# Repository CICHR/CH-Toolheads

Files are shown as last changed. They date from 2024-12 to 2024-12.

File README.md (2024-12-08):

CICHR Toolheads

The changeable toolheads are designed for maximum versatility and seamless integration, communicating directly with the printer via a custom PCB. This PCB enables precise control and coordination between the tool head and the printer, ensuring fast, accurate swaps between different functions. The custom PCB features:

    Heater and High-Power Outputs:
    Two high-power outputs for heaters or PWM-controlled devices with demanding power requirements.

    Temperature Sensing:
    Two thermistor inputs for accurate real-time temperature monitoring.

    PWM Outputs:
    Two PWM outputs for controlling servos, BLTouch sensors, or cooling fans.

    Digital Interfaces:
    One digital input and one digital output for additional functionality, such as endstops or status signaling.

    Stepper Motor Control:
    A dedicated output for driving a single stepper motor, ideal for toolhead-mounted extrusion or positioning tasks.

    Streamlined Communication:
    Ensures reliable communication between the toolhead and the machine, simplifying toolhead management and enhancing modularity.

This system allows you to quickly swap between different toolheads, such as 3D printing extruders, CNC milling tools, lasers, or liquid extruders, without complex rewiring, while maintaining full control over key functions.

Visit our website at www.cichr.com or https://grabcad.com/cichr-1 to learn more about our products, projects, and innovations.

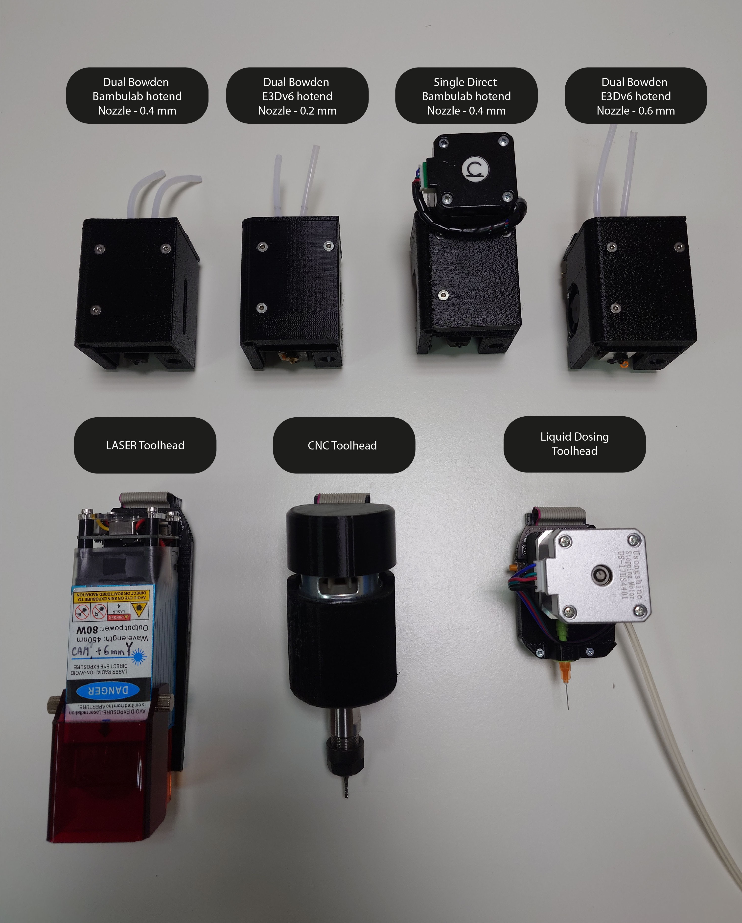
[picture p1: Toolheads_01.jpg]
CH-Toolheads


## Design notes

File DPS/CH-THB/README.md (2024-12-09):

CH-THB: The Versatile Toolhead PCB

The CH-THB is a specialized PCB board designed to manage and control a single toolhead, seamlessly connecting it to the main machine control system. This board is highly versatile, supporting various toolhead types, including 3D printers, lasers, routers, and more.

  Key Features:

      Heater and High-Power Outputs:
        Two high-power outputs for heaters or PWM-controlled devices with demanding power requirements.
      Temperature Sensing:
        Two thermistor inputs for accurate real-time temperature monitoring.
      PWM Outputs:
        Two PWM outputs for controlling servos, BLTouch sensors, or cooling fans.
      Digital Interfaces:
        One digital input and one digital output for additional functionality, such as endstops or status signaling.
      Stepper Motor Control:
        A dedicated output for driving a single stepper motor, ideal for toolhead-mounted extrusion or positioning tasks.
      Streamlined Communication:
        Ensures reliable communication between the toolhead and the machine, simplifying toolhead management and enhancing modularity.

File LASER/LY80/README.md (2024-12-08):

The CH-LASER-LY80 toolhead is a versatile and powerful laser module, perfect for cutting and engraving a wide range of materials with precision and efficiency. Featuring the LUNYEE 80W blue diode laser with a 10W optical power output, it delivers exceptional accuracy for both hobbyists and professionals. A built-in WiFi camera ensures precise alignment and real-time monitoring for flawless results.

    Cutting Capabilities:
    All types of paper, carton, fabric, leather, and plastics (note: NEVER laser PVC as it releases toxic fumes).
    Soft and medium-hard woods up to 10–12mm with multiple passes; 3–5mm achievable in a single pass.
    Black and certain colored acrylics up to 5mm with ease, 10mm depending on the color (clear acrylic cannot be cut due to the laser's light frequency).

    Engraving Capabilities:
    Almost all non-metallic materials.
    Stainless steel and ceramics with remarkable precision.

The CH-LASER-LY80 is the perfect toolhead for achieving high-quality cuts and engravings across a wide variety of projects.

Visit our website at www.cichr.com or https://grabcad.com/cichr-1 to learn more about our products, projects, and innovations.

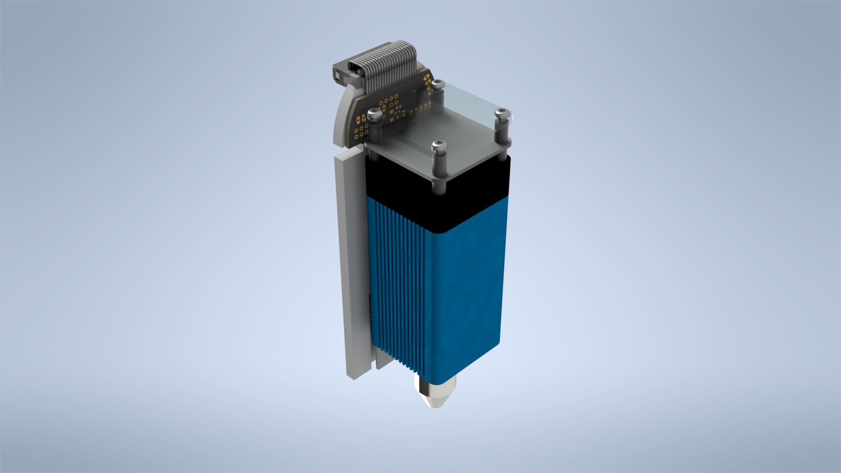
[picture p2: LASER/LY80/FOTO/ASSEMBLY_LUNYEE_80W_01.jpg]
CH-LASER-LY80


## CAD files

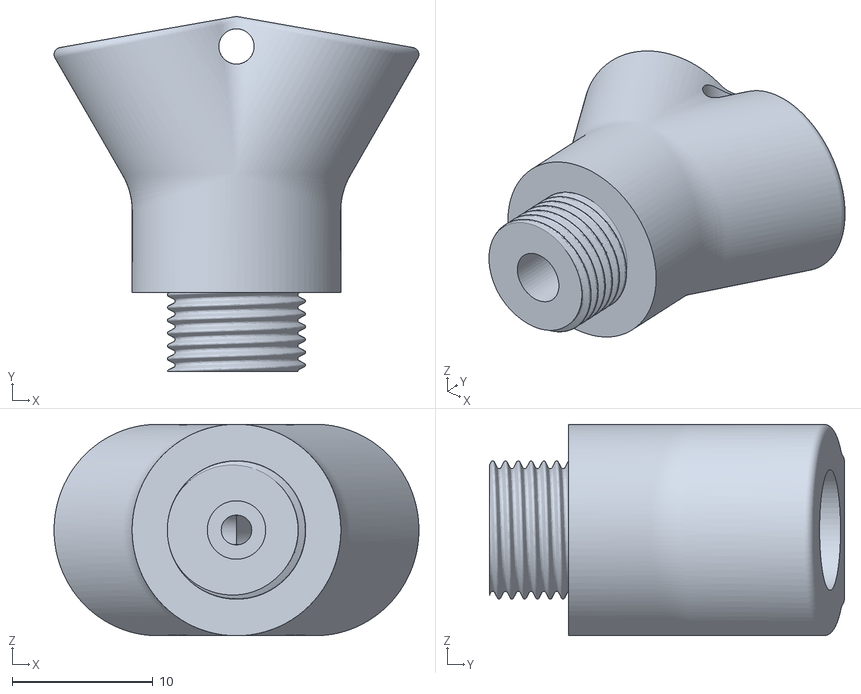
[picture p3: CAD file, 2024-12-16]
3D_PRINT/E3D_BOWDEN/STL/E3Dv6_DUAL_FITTING.stl
25.9 x 25.2 x 15.0

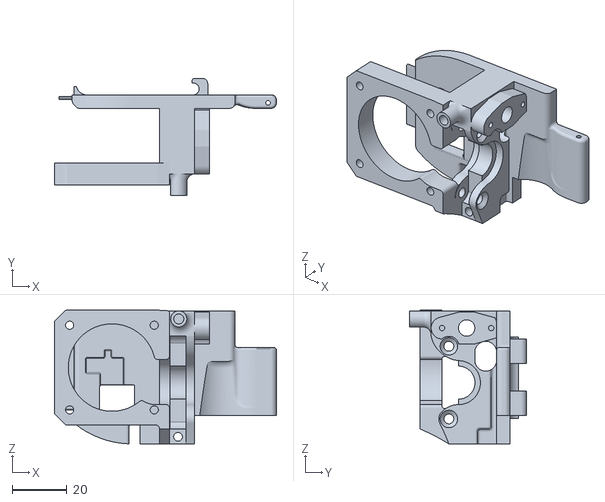
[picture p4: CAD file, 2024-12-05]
3D_PRINT/E3D_DIRECT/STL/E3Dv6_DIRECT_BASE.stl
81.3 x 43.0 x 49.0

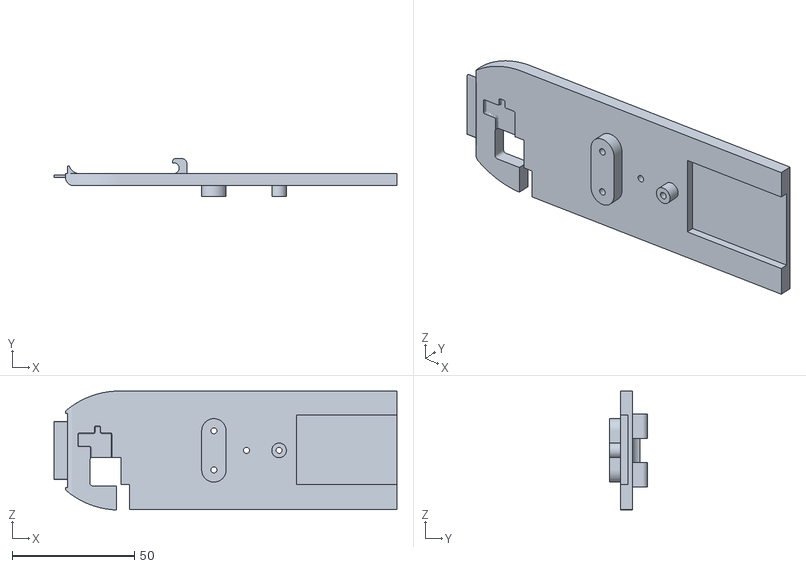
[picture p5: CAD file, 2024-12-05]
LASER/LY80/STL/X_Mount_LUNYEE_80W.stl
140.5 x 15.5 x 48.7

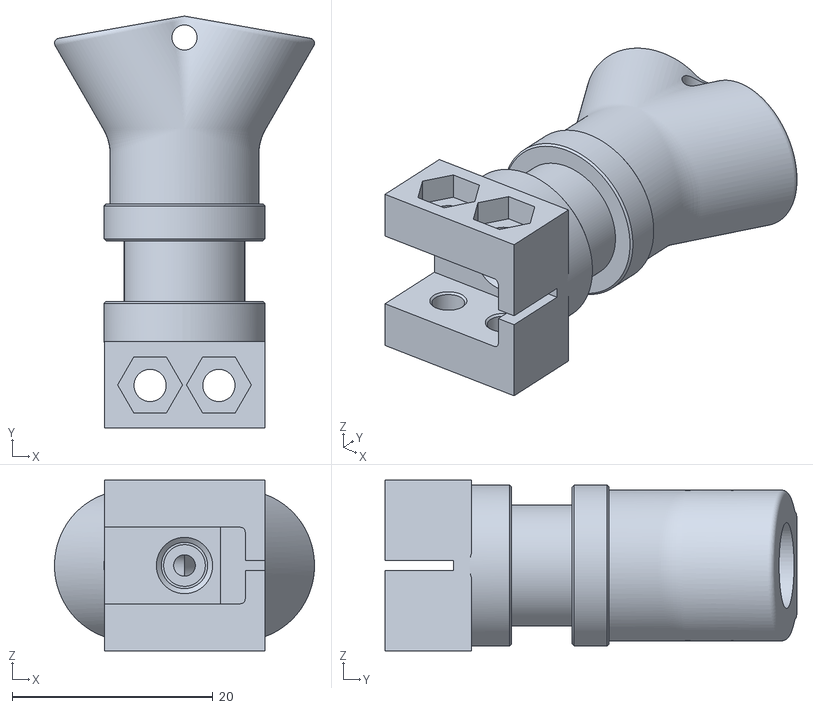
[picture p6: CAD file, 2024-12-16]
3D_PRINT/E3D_BOWDEN/STL/ADAPTER_BAMBU-E3D_DUAL_FITTING.stl
25.9 x 41.0 x 17.0

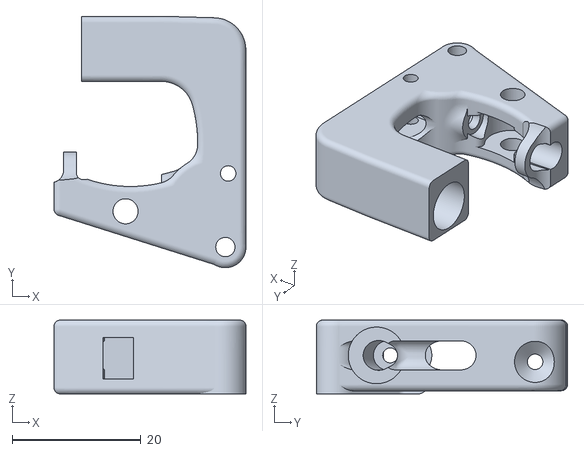
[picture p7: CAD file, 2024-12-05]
3D_PRINT/E3D_DIRECT/STL/E3Dv6_DIRECT_TENSIONER_II.stl
29.9 x 39.1 x 11.5

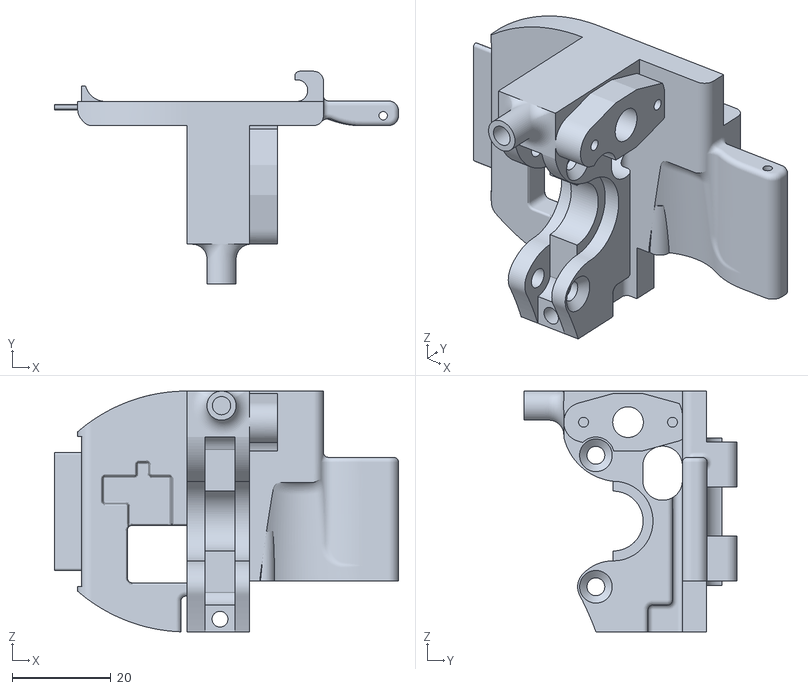
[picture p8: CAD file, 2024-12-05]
3D_PRINT/E3D_BOWDEN/STL/E3Dv6_BOWDEN_BASE.stl
69.6 x 43.0 x 48.7

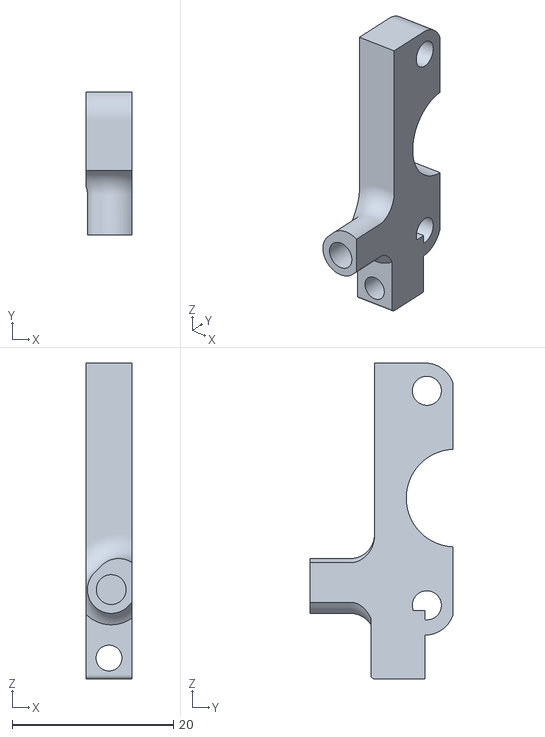
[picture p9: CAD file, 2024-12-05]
3D_PRINT/E3D_DIRECT/STL/E3Dv6_DIRECT_BASE_Bracket.stl
5.75 x 17.8 x 39.2

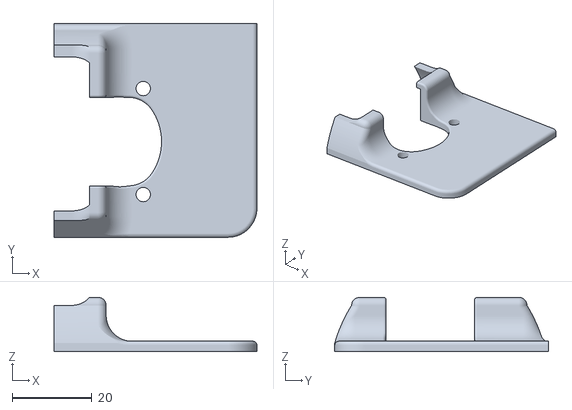
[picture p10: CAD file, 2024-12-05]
3D_PRINT/E3D_BOWDEN/STL/E3Dv6_BOWDEN_HOUSING_Top_DUAL.stl
50.9 x 53.6 x 13.6

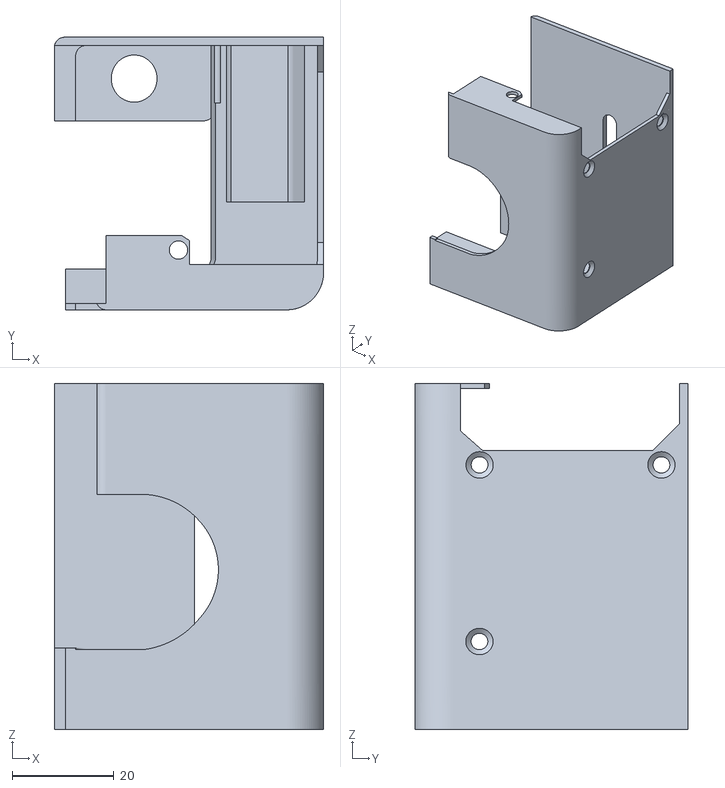
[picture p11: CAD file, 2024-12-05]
3D_PRINT/E3D_DIRECT/STL/E3Dv6_DIRECT_HOUSING_Side.stl
53.0 x 53.6 x 68.0

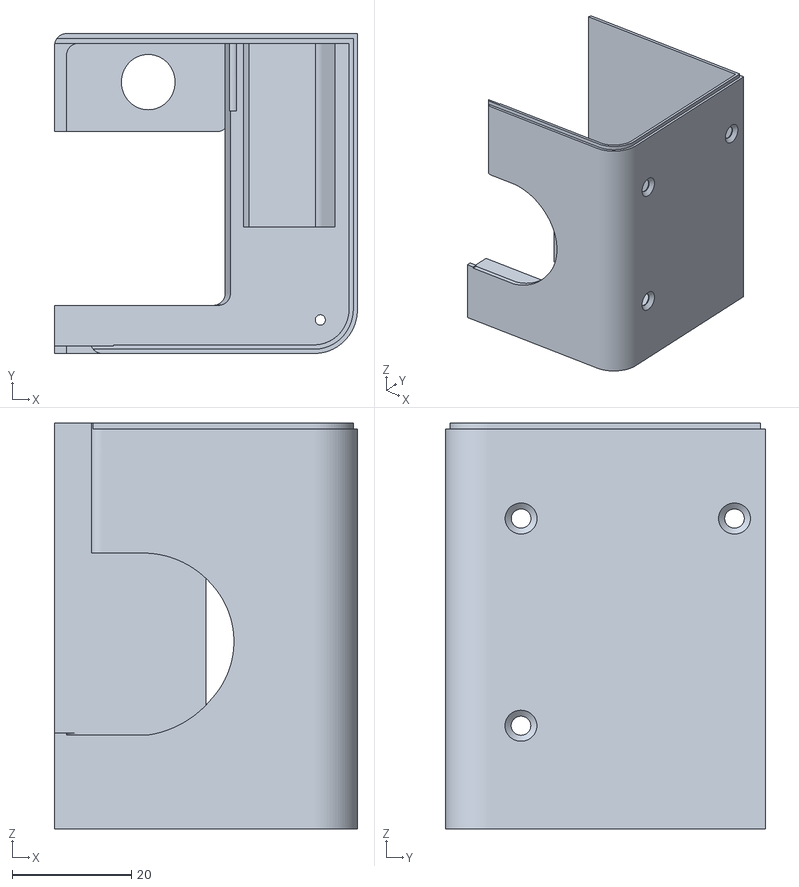
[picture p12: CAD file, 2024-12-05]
3D_PRINT/E3D_BOWDEN/STL/E3Dv6_BOWDEN_HOUSING_Side.stl
50.8 x 53.6 x 68.0

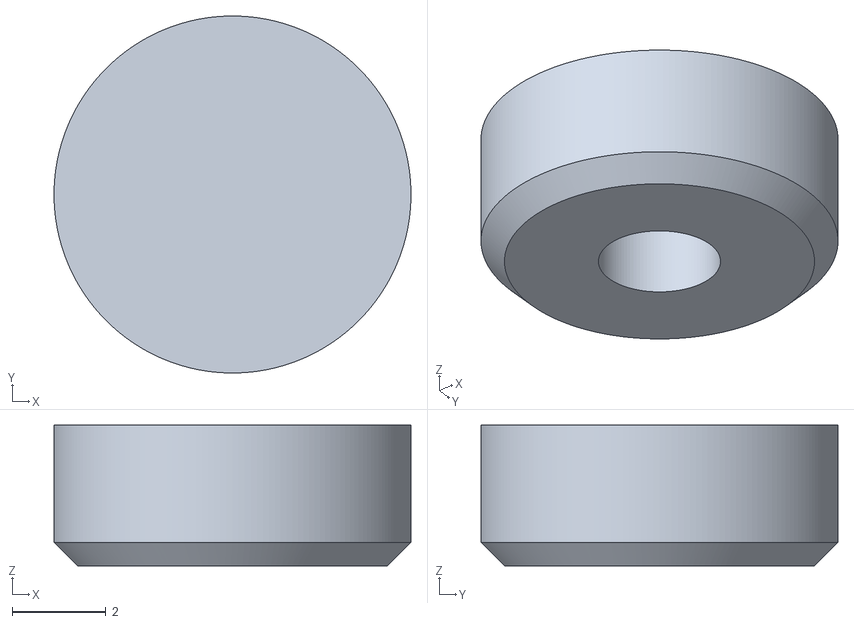
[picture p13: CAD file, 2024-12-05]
3D_PRINT/E3D_DIRECT/STL/E3Dv6_DIRECT_LoadPad.stl
7.60 x 7.60 x 3.00

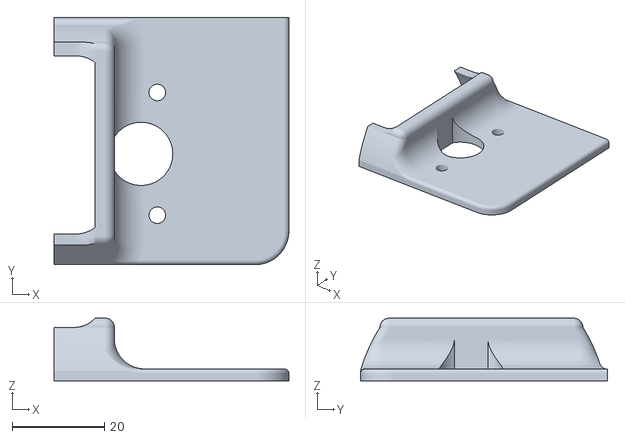
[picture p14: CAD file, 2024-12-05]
3D_PRINT/E3D_BOWDEN/STL/E3Dv6_BOWDEN_HOUSING_Top_SINGLE.stl
50.9 x 53.6 x 13.6

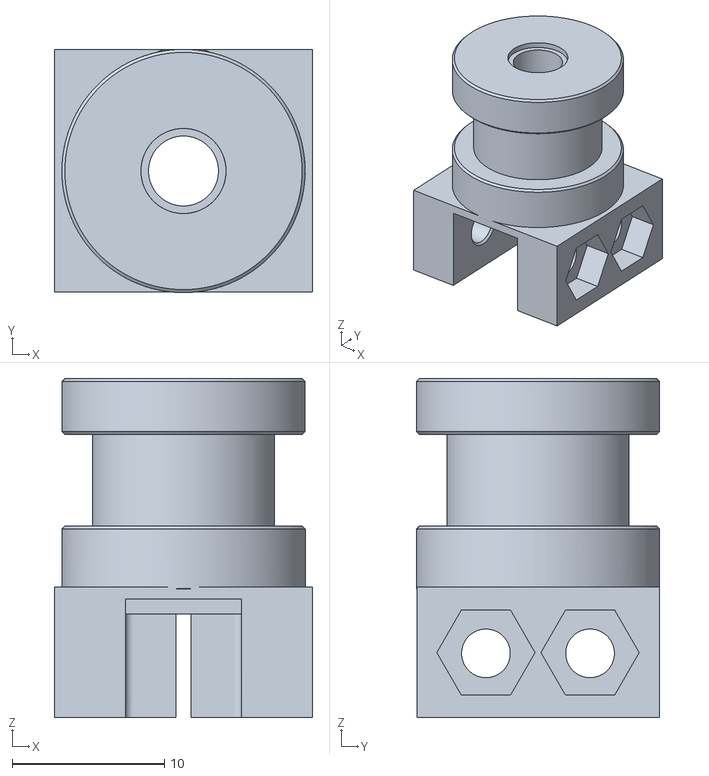
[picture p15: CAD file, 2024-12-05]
3D_PRINT/E3D_DIRECT/STL/ADATPER_BAMBU-E3D.stl
17.0 x 16.0 x 22.3

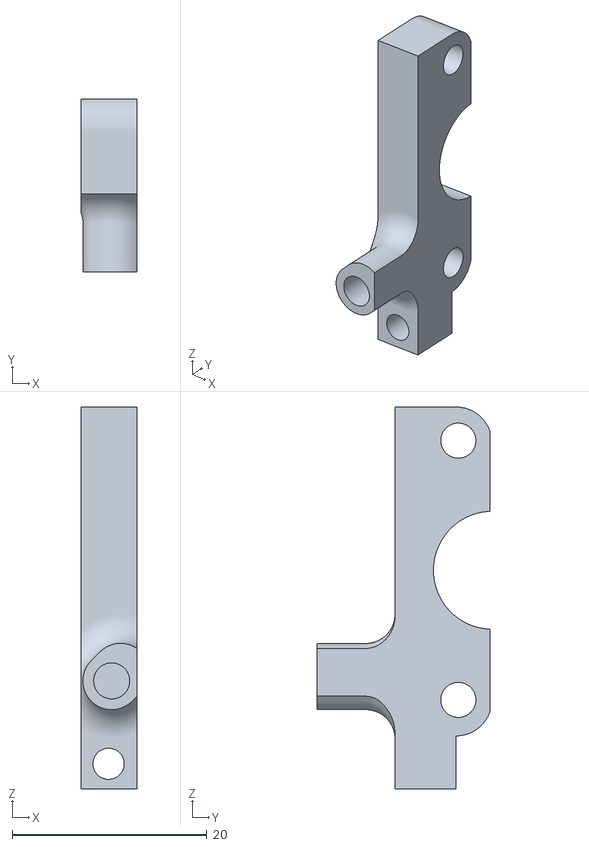
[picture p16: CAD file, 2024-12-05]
3D_PRINT/E3D_BOWDEN/STL/E3Dv6_BOWDEN_BASE_Bracket.stl
5.75 x 17.8 x 39.2

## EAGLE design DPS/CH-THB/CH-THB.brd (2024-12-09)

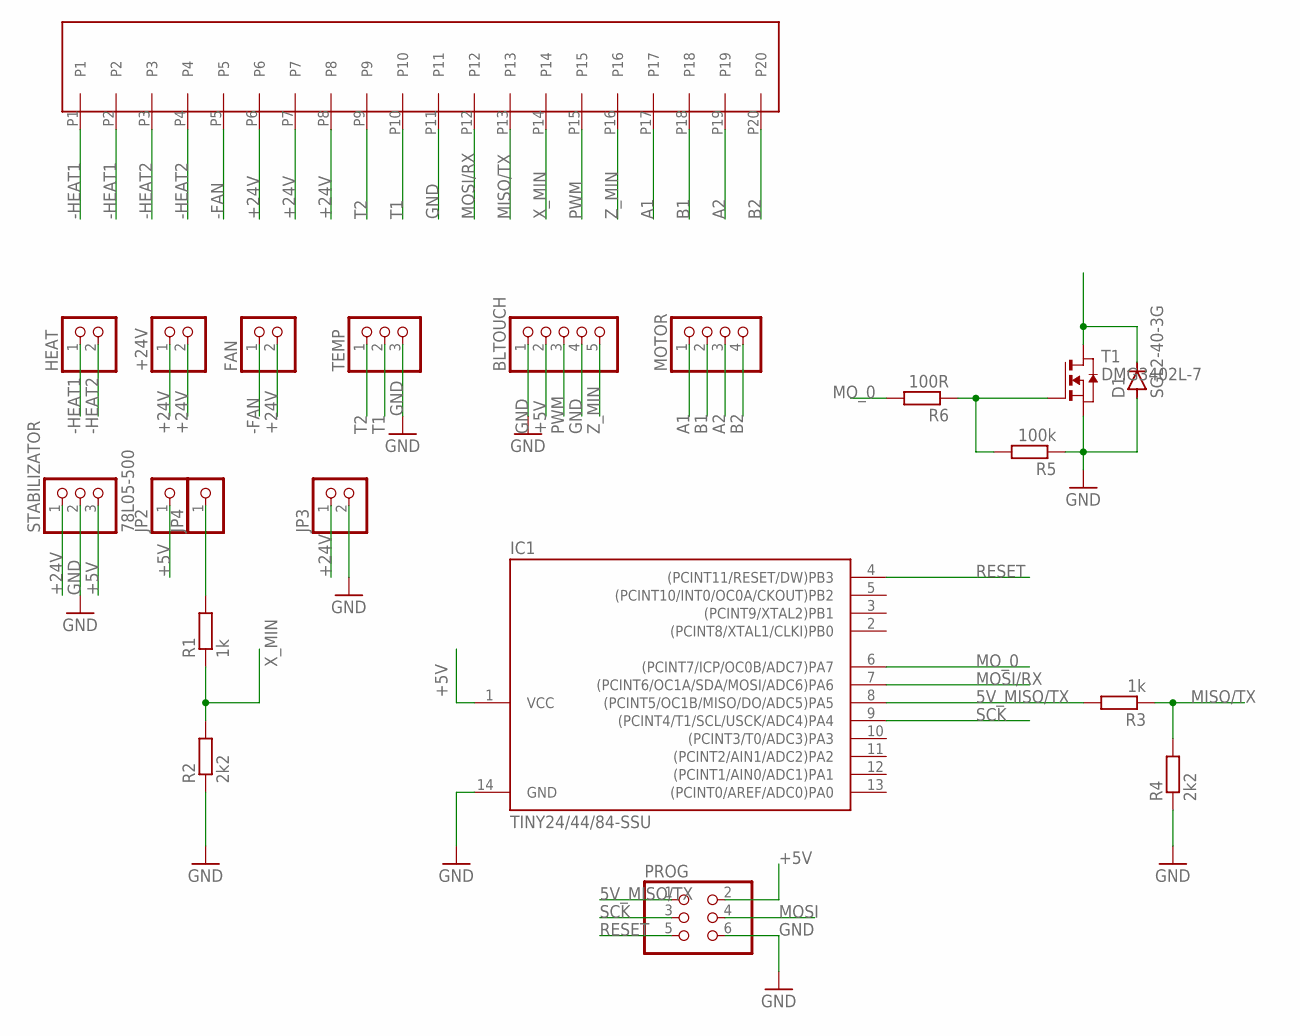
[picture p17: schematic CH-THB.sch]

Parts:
+24V: PINHD-1X2/LONG; 1X02
BLTOUCH: PINHD-1X5/LONG; 1X05
D1: SGL2-40-3G; SOD80
FAN: PINHD-1X2/LONG; 1X02
HEAT: PINHD-1X2/LONG; 1X02
IC1: TINY24/44/84-SSU; SOIC14
JP2, JP4: PINHD-1X1/OCT; 1X01/OCT
JP3: PINHD-1X2/OCT; 1X02/OCT
MOTOR: PINHD-1X4/LONG; 1X04
PROG: PINHD-2X3/OCT; 2X03
R1, R3: 1k; R0603
R2, R4: 2k2; R0603
R5: 100k; R0603
R6: 100R; R0603
STABILIZATOR: 78L05-500; 1X03/OCT
T1: DMG3402L-7; SOT-23
TEMP: PINHD-1X3/OCT; 1X03/OCT
U$1: PL20

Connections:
5V_MISO/TX: IC1.8 ((PCINT5/OC1B/MISO/DO/ADC5)PA5), PROG.1, R3.2
+5V: BLTOUCH.2, IC1.1 (VCC), JP2.1, PROG.2, STABILIZATOR.3
+24V: +24V.1, +24V.2, FAN.2, JP3.1, STABILIZATOR.1, U$1.P6, U$1.P7, U$1.P8
-FAN: FAN.1, U$1.P5
-HEAT1: HEAT.1, U$1.P1, U$1.P2
-HEAT2: HEAT.2, U$1.P3, U$1.P4
A1: MOTOR.1, U$1.P17
A2: MOTOR.3, U$1.P19
B1: MOTOR.2, U$1.P18
B2: MOTOR.4, U$1.P20
GND: BLTOUCH.1, BLTOUCH.4, D1.2 (A), IC1.14 (GND), JP3.2, PROG.6, R2.1, R4.1, R5.1, STABILIZATOR.2, T1.2 (S), TEMP.3, U$1.P11
MISO/TX: R3.1, R4.2, U$1.P13
MOSI: PROG.4
MOSI/RX: IC1.7 ((PCINT6/OC1A/SDA/MOSI/ADC6)PA6), U$1.P12
MO_0: IC1.6 ((PCINT7/ICP/OC0B/ADC7)PA7), R6.2
unnamed: JP4.1, R1.2
unnamed: R5.2, R6.1, T1.3 (G)
unnamed: D1.1 (C), T1.1 (D)
PWM: BLTOUCH.3, U$1.P15
RESET: IC1.4 ((PCINT11/RESET/DW)PB3), PROG.5
SCK: IC1.9 ((PCINT4/T1/SCL/USCK/ADC4)PA4), PROG.3
T1: TEMP.2, U$1.P10
T2: TEMP.1, U$1.P9
X_MIN: R1.1, R2.2, U$1.P14
Z_MIN: BLTOUCH.5, U$1.P16

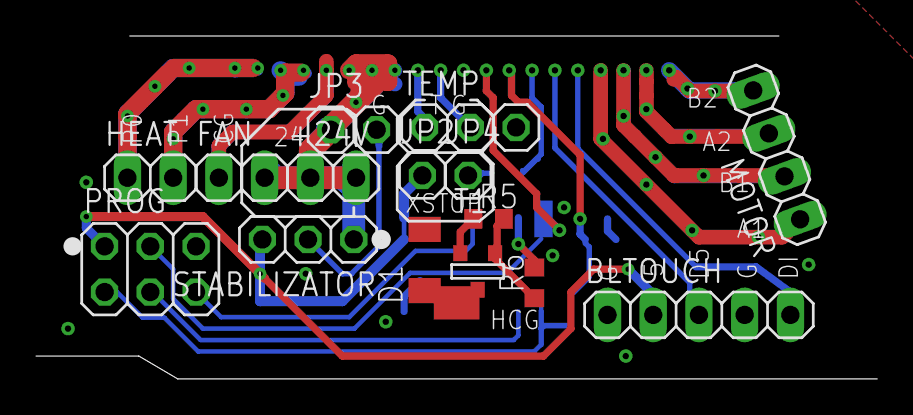
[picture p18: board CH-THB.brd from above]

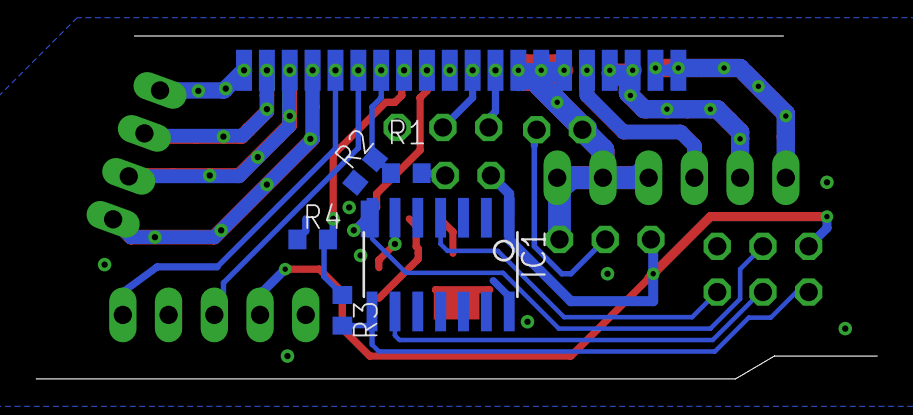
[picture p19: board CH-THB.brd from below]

Board: 2 copper layers, 46.7 x 19.0 mm, 21 parts (6 on the bottom side), 24 nets.

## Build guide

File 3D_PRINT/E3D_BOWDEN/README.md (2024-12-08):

CICHR Toolhead CH-Bowden and CH-DualBowden

The CH-E3Dv6-Bowden toolhead is a versatile and reliable solution for 3D printing, featuring the trusted E3Dv6 hotend. It supports both single and dual Bowden extruder configurations, providing flexibility for various printing needs. The Bowden setup ensures lightweight, fast movement for precise and high-quality prints. Additionally, the toolhead includes a BLTouch sensor for automatic bed leveling and a dedicated cooling fan to ensure efficient part cooling during prints, enhancing overall performance and print quality.

Visit our website at www.cichr.com or https://grabcad.com/cichr-1 to learn more about our products, projects, and innovations.

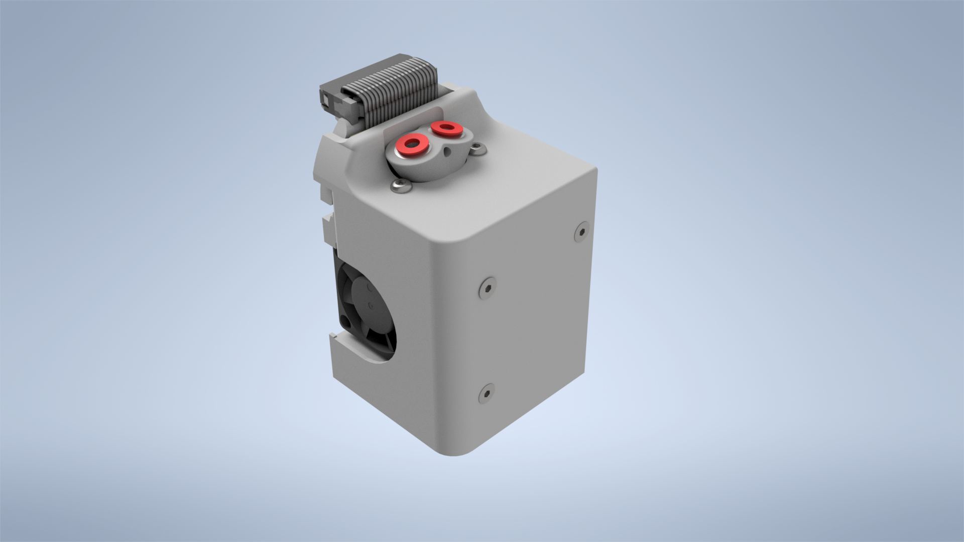
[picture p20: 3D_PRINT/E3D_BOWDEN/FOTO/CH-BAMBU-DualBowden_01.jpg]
CH-BOWDEN


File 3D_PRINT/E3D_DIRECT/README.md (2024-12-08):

CICHR Toolhead CH-Direct

The CH-Direct toolhead is designed for exceptional precision and reliability, featuring the trusted E3Dv6 hotend in a robust direct drive configuration. Ideal for handling a wide range of filament types, including flexible materials like TPU and TPE, the direct drive system provides precise extrusion control with minimal retraction requirements.

The toolhead includes a BLTouch sensor for automatic bed leveling, ensuring consistent first-layer quality, and a dedicated cooling fan for efficient part cooling during prints. Its compact design reduces filament path length, enhancing responsiveness and improving overall extrusion accuracy. Whether you're printing intricate details or experimenting with advanced materials, the CH-Direct toolhead delivers reliable performance every time.

Visit our website at www.cichr.com or https://grabcad.com/cichr-1 to learn more about our products, projects, and innovations.

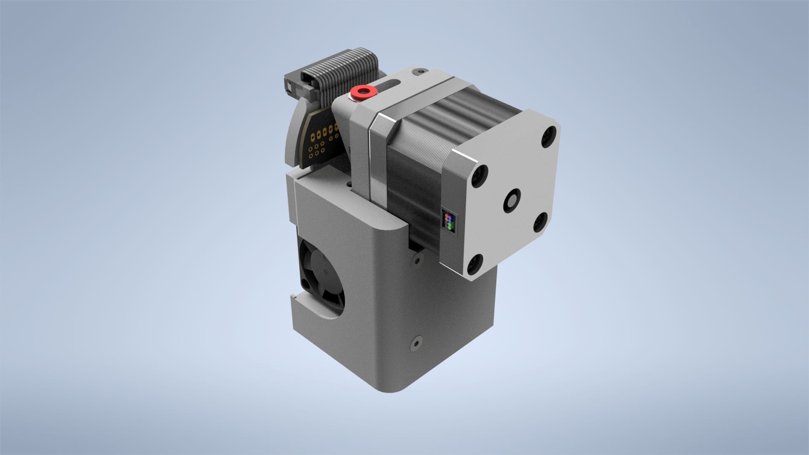
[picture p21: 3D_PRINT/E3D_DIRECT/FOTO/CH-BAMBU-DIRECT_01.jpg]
CH-DIRECT


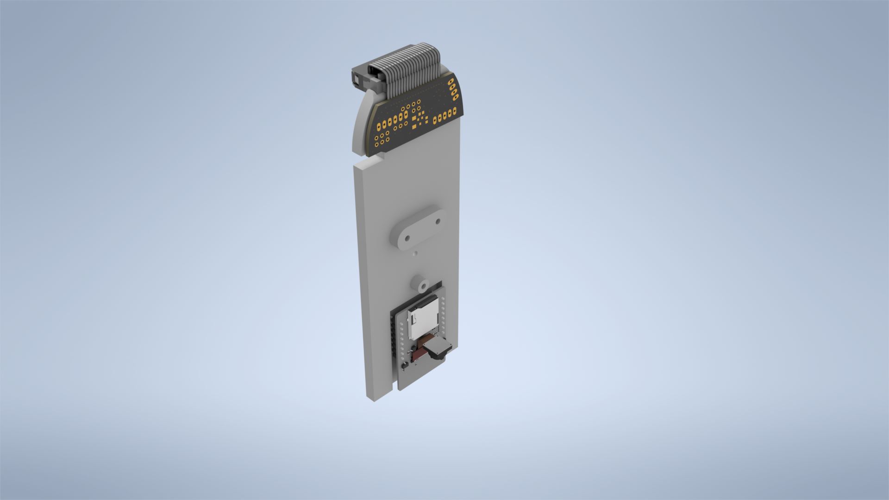
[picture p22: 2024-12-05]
LASER/LY80/FOTO/ASSEMBLY_LUNYEE_80W_02.jpg

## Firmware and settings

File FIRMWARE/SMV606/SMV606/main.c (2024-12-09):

/*
 * SMV606.c
 *
 * Created: 05.03.2022 19:30:57
 * Author : cichy
 */ 
#define F_CPU 8000000UL
#include <avr/io.h>
#include <util/delay.h>
#include "lib/USI_UART/USI_UART.h"
#include <string.h>

#define received_msg_size 4
#define which_head "HHD"
#define head_confirm "HOK"
#define head_out0_ON "H0I"
#define head_out0_OFF "H0O"

#define head_code "SMV606.g"
#define message_tool "FDM"		//MAX 10 Znaku

#define out0 PA7

void IO_init(void) {
	DDRA |= (1 << out0);  // Set PA7 as an output pin
	PORTA &= ~ (1 << out0);  // Set PA7 low
}



int main(void) {
	IO_init();
	USI_UART_init();		// set up pin directions, flush buffers, etc
	char received_msg[received_msg_size];
	uint8_t pos = 0;
	uint8_t received_byte;
	USI_UART_Initialise_Transmitter();
	_delay_ms(10);
	for(;;) {
		while(USI_UART_Data_In_Receive_Buffer()) {
			received_byte = USI_UART_Receive_Byte();
			if (received_byte == '\n') {
				received_msg[pos] = '\0';  // Null-terminate the string
				
				if (pos > 0 && received_msg[pos - 1] == '\r') {
					received_msg[pos - 1] = '\0';
				}
				
				if (pos == 0 && received_byte != 'H') {
					// If the first byte is not 'H', reset the buffer position
					pos = 0;
					continue;
				}
				
				if (strcmp(received_msg, which_head) == 0) {
					USI_UART_Transmit_Byte('\n');
					_delay_ms(5);
					USI_UART_puts("M98 P");
					USI_UART_Transmit_Byte(0x22);
					USI_UART_puts(head_code);
					USI_UART_Transmit_Byte(0x22);
					USI_UART_Transmit_Byte('\n');
					
					} else if (strcmp(received_msg, head_confirm) == 0) {
					USI_UART_Transmit_Byte('\n');
					_delay_ms(5);
					USI_UART_puts("M118 P0 L1 S");
					USI_UART_Transmit_Byte(0x22);
					USI_UART_puts(message_tool);
					USI_UART_Transmit_Byte(0x22);
					USI_UART_Transmit_Byte('\n');
					
					} else if (strcmp(received_msg, head_out0_ON) == 0) {
					PORTA |=  (1 << out0);  // Set PA7 high
					
					} else if (strcmp(received_msg, head_out0_OFF) == 0) {
					PORTA &= ~ (1 << out0);  // Set PA7 low
				}
				
				pos = 0;  // Reset buffer position
				
				} else {
				if (pos < sizeof(received_msg) - 1) {  // Prevent buffer overflow
					received_msg[pos++] = received_byte;
					} else {
					pos = 0;  // Reset buffer position
				}
			}
		}
	}
}
